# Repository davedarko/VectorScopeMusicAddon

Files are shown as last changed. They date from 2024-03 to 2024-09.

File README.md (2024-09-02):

# VectorScopeMusicAddon
A small add-on for the Hackaday Supercon 2023 / Europe 2024 event badge that allows displaying oscilloscope music!

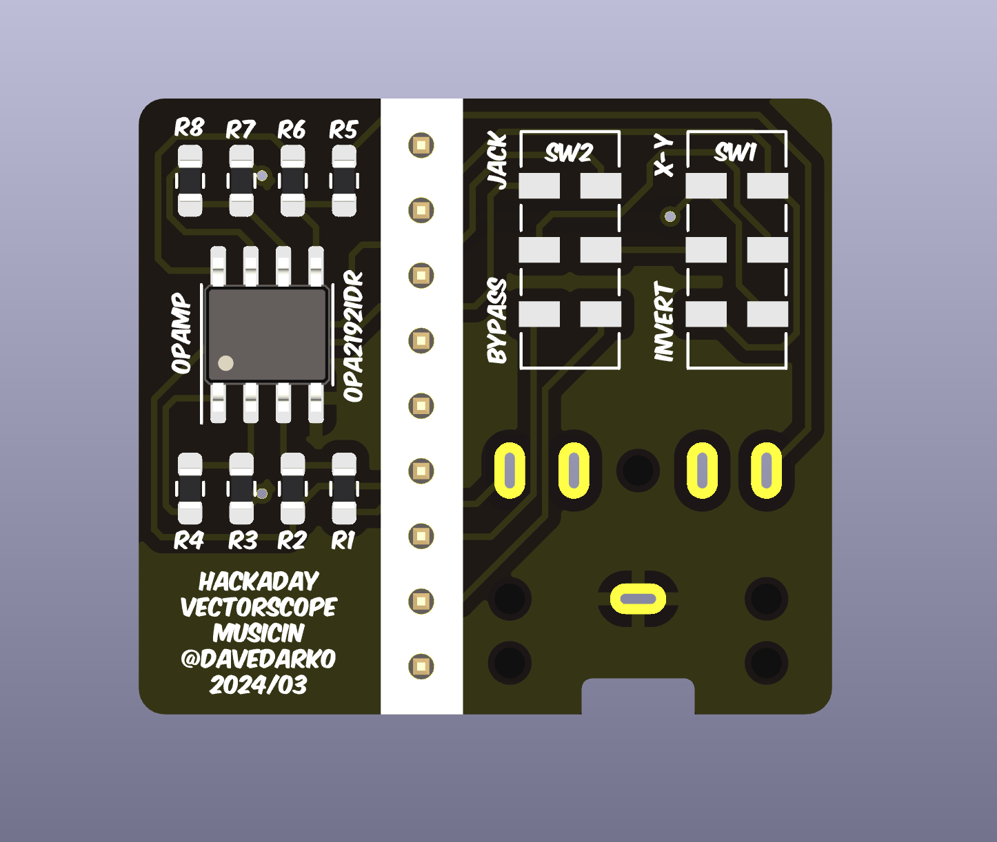
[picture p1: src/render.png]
Screenshot of KiCad render


## Design Notes
There's a switch to flip the x and y-axis. Due to the displays coordinate system being 0,0 top-left it means that the y-axis is mirrored or upside-down. To negate this in some way and not fiddle around with inverting signals, the switch rotates the image by 90 degrees. It might just be that one of my macbooks channels is inverted, I have to investigate.

## Errata
There's an easy fix for the vectorscope having an inverted y-axis, making the oscilloscope music show upside down. I've created a software PR that rotates and mirrors the display so it's looking correct on its own. Luckily the oscilloscope mode has running its own display instance, so it is one line of code to change.

https://github.com/Hack-a-Day/Vectorscope/pull/15

## BASIC-2
There's a wonderful case design for the badge done by @softegg. To fit into the badge better, I have designed another version with no parts on the left side of the pin header and mounting holes to create a small 3D printed cover to fit the theme better. With the known fix for the inverted y-axis, I have removed the switch to swap x and y axis now.

https://github.com/softegg/supercon-2023-badge-enclosure/

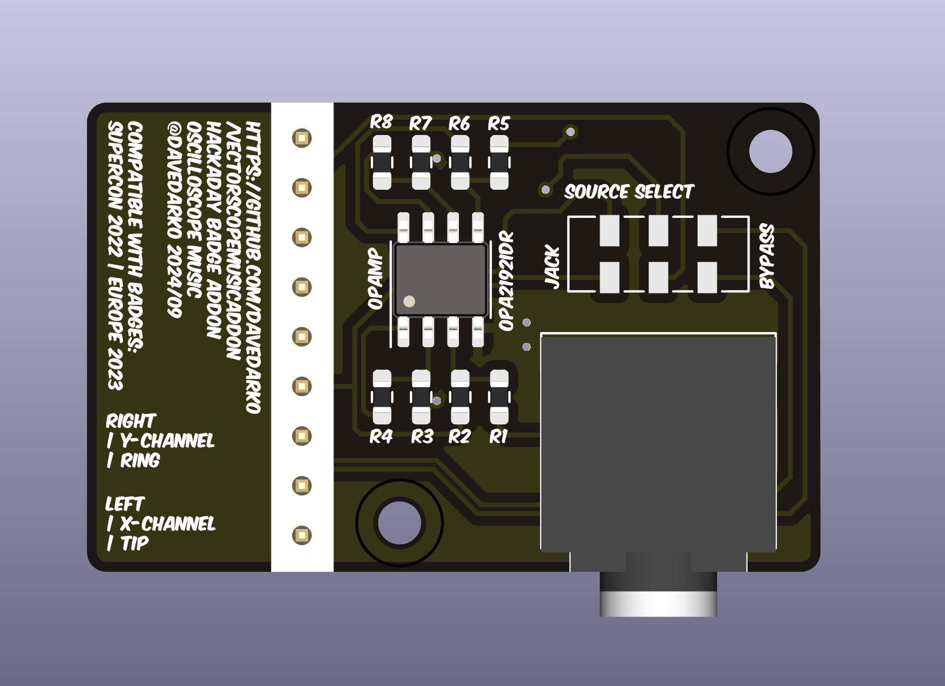
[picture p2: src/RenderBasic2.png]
Screenshot of KiCad render


## credits
- Hackaday's badge repo https://github.com/Hack-a-Day/Vectorscope
- schematics are heavily inspired by this post https://electronics.stackexchange.com/questions/37095/level-shifting-a-2-5v-signal-to-0-5v

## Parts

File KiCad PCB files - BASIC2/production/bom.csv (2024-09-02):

Designator | Footprint | Quantity | Value | LCSC Part #
J1 | PinHeader_1x09_P2.54mm_Vertical | 1 | Conn_01x09_Socket
J3 | Jack_3.5mm_CUI_SJ1-3525N_Horizontal | 1 | AudioJack3_SwitchTR
R1, R5 | 0603 | 2 | 10k
R2, R6 | 0603 | 2 | 33k
R3, R7 | 0603 | 2 | 13k
R4, R8 | 0603 | 2 | 15k
SW2 | SW_DPDT_CK_JS202011JCQN | 1 | SW_Push_DPDT | C221665
U1 | SOIC-8_3.9x4.9mm_P1.27mm | 1 | OPA2192 | C110074

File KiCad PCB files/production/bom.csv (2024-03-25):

Designator | Footprint | Quantity | Value | LCSC Part #
J1 | PinHeader_1x09_P2.54mm_Vertical | 1 | Conn_01x09_Socket
J3 | Jack_3.5mm_CUI_SJ1-3525N_Horizontal | 1 | AudioJack3_SwitchTR
R1 | 0603 | 1 | 10k
R2 | 0603 | 1 | 33k
R3 | 0603 | 1 | 13k
R4 | 0603 | 1 | 15k
R5 | 0603 | 1 | 10k
R6 | 0603 | 1 | 33k
R7 | 0603 | 1 | 13k
R8 | 0603 | 1 | 15k
SW1, SW2 | SW_DPDT_CK_JS202011JCQN | 2 | SW_Push_DPDT | C221665
U1 | SOIC-8_3.9x4.9mm_P1.27mm | 1 | OPA2192 | C110074

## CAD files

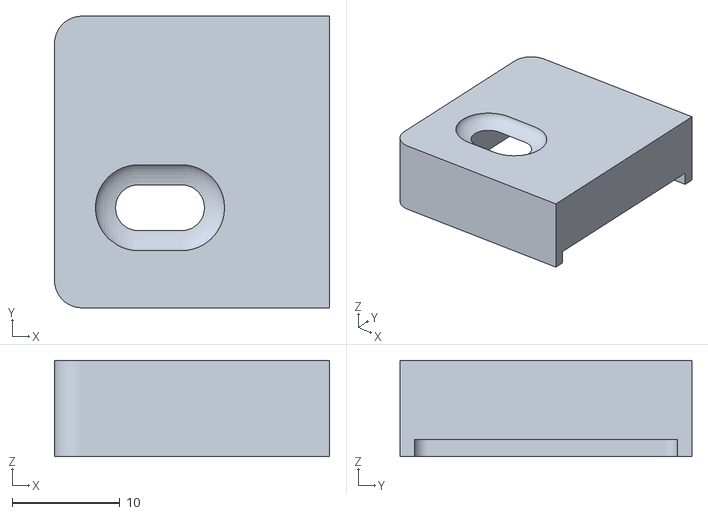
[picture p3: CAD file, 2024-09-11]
KiCad PCB files - BASIC2/Case/BASIC2.stl
25.5 x 27.1 x 8.95

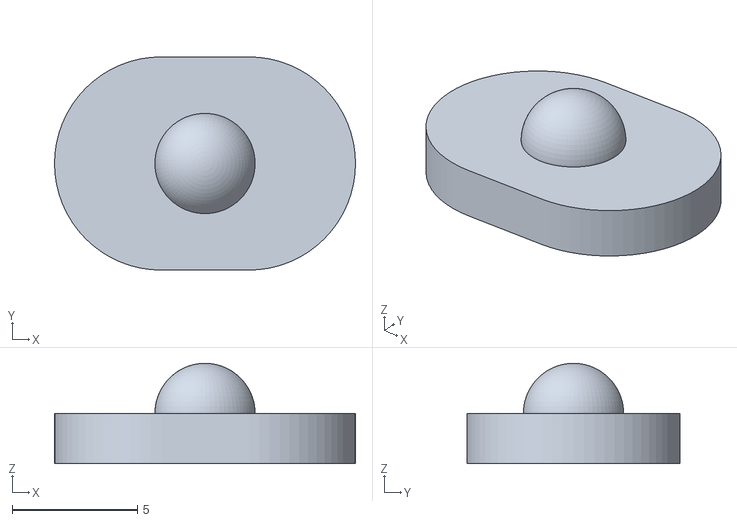
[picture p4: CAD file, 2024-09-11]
KiCad PCB files - BASIC2/Case/BASIC2_switch.stl
12.0 x 8.50 x 4.00

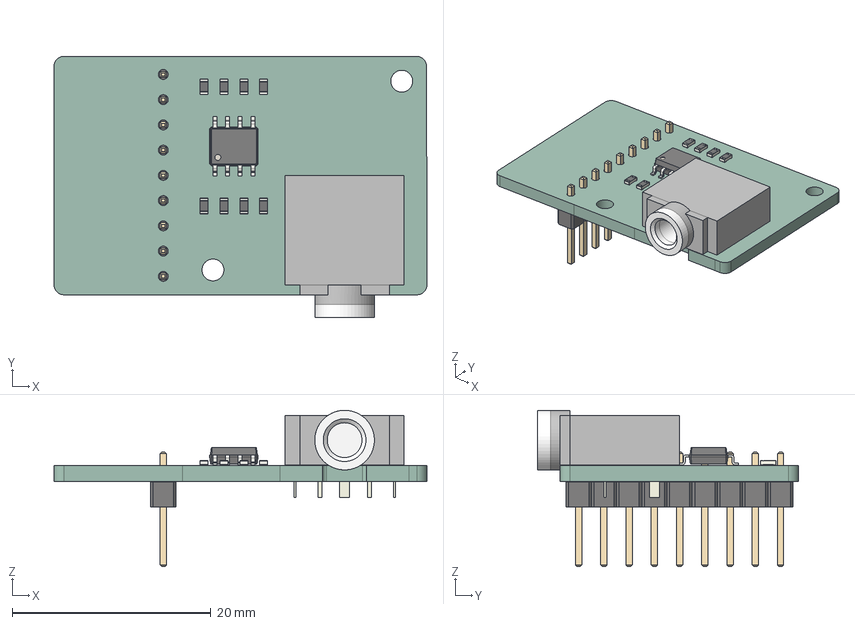
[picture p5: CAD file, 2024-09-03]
KiCad PCB files - BASIC2/Case/VectorScopeMusicAddon.step
37.5 x 26.3 x 15.7 mm
R_0603_1608Metric x 8
Jack_3.5mm_CUI_SJ1-3525N_Horizontal
SOIC_8_39x49mm_P127mm
PinHeader_1x09_P254mm_Vertical
VectorScopeMusicAddon_PCB

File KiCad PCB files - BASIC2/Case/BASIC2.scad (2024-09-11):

w = 37.5;
d = 24;
h = 1.6;
r = 1;
$fn = $preview ? 32 : 64;


t = 3 * .45; // thickness of walls
c = .2; // clearance
case =  t*2 + c*2;
ch = 6 + h + t; // - (r+t+c);


cube_w = 9;
cube_d = 3.7;
cube_h = 3.7;

button_w = 11;
button_d = 8.5;
button_h = 2;
button_r = button_d/2;
button_s = 2;
button_c = 1.8;
	

if($preview) {

	// PCB
	color("green")
	difference() {		
		rounded_box(w,d,h,r);
		
		translate([-w/2 + (w-35), -d/2 + 2.5, -1])
		cylinder(h+2, 1.1, 1.1);
		
		translate([-w/2 + (w-35) + 19, -d/2 + 2.5 + 19, -1])
		cylinder(h+2, 1.1, 1.1);
	}
	
	jack();
	
	// switch cutout
	translate([-cube_w/2 + w/2 -29.25,-cube_d/2 -d/2 +7.75, h]) 
	cube([cube_w,cube_d,cube_h]);
}

if(1) {

	color ([1,1,1,.3])
	// button
	translate([ button_s/2 + w/2 -29.25,-d/2 +7.75, h + cube_h]) {

		difference() {
			union() {
				rounded_box(button_w,button_d,button_h,button_r);
				
				translate([0,0,button_h])
				sphere(button_s);
			}
			
			
			translate([-button_c/2,-button_c/2,-1])
			cube([button_c, button_c, button_h + button_s/2 + 1]);
		}
	}
	 
}

// case
if (1)
color ([.1,.1,.1,.5]) {
	union () {

		difference() {

			union() {
				rounded_box(w + case, d + case, ch, r+ case/2);
				
				if (0) {
				// cylinder();
				translate([-w/2 + r, -d/2 + r, ch])
				sphere(r+case/2);
				
				translate([-w/2 + r, d/2 - r, ch])
				sphere(r+case/2);
				
				translate([-w/2  + r, d/2 - r, ch])
				rotate([0,90,0])
				cylinder(w, r+case/2, r+case/2);

				translate([-w/2  + r, -d/2 + r, ch])
				rotate([0,90,0])
				cylinder(w, r+case/2, r+case/2);

				translate([
					-(w + case)/2 +(r+t+c), 
					+(d + case)/2 -(r+t+c),
					ch
					])
				rotate([90,0,0])
				cylinder((d + case) - 2* (r+t+c) , r+case/2, r+case/2);

				}			
			}
			
			pill_w = 12;
			pill_r = 4;
			translate([pill_w/2 + w/2 -29.25, -d/2 +7.75, ch])
						scale([1,1,.4])
			rotate([0,-90,0])
				pill(pill_w, pill_r);


			
			translate([0, 0, -1]) 
			rounded_box(w + c*2, d + c*2, ch - t + 1, r + c);
			
			

			translate([ - w/2 + 24, -d, -1]) 	
			cube([2*w, 2*d, 2*ch +1]);
			
			jack();
		}
		
		// wall
		translate([1*.45 - t - w/2 + 24, -(d+case)/2,h])
		cube([t- 1*.45, d + case, ch-h]);

		// screw terminals
		difference() {
			translate([-w/2 + (w-35), -d/2 + 2.5, h])
			cylinder(ch-h, 2.5, 2.5);

			translate([-w/2 + (w-35), -d/2 + 2.5, h-1])
			cylinder(ch-h+2, .8, .8);
		}

		difference() {
			translate([-w/2 + (w-35) + 19, -d/2 + 2.5 + 19, h])
			cylinder(ch-h, 2.5, 2.5);

			translate([-w/2 + (w-35) + 19, -d/2 + 2.5 + 19, h-1])
			cylinder(ch-h+2, .8, .8);
		}
		
	}
}




// jack
module jack() {
	color("gray")
	translate([+w/2 -6 -29.25,0,h]) {
		cube([12,12,5]);
		
		translate([6, 12 + 3.3, 2.5])
		rotate([90,0,0])
		cylinder(3.3, 3.1, 3.1);
	}
}

module pill(h, r){
	translate([0,0,r]) {
		sphere(r);
		cylinder(h-r-r,r,r);
		translate([0,0,h-r-r])
		sphere(r);
	}
}

module rounded_box(w,d,h,r)
{
	union(){
		translate([-w/2+r, -d/2+r, 0]) cylinder(h, r, r);
		translate([-w/2+r, d/2-r, 0]) cylinder(h, r, r);
		translate([w/2-r, -d/2+r, 0]) cylinder(h, r, r);
		translate([w/2-r, d/2-r, 0]) cylinder(h, r, r);
		
		translate([-w/2+r, -d/2, 0]) cube([w-r*2,d,h]);
		translate([-w/2, -d/2+r, 0]) cube([w,d-r*2,h]);
	}
}

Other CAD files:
KiCad PCB files - BASIC2/Case/BASIC2_fillet.stl

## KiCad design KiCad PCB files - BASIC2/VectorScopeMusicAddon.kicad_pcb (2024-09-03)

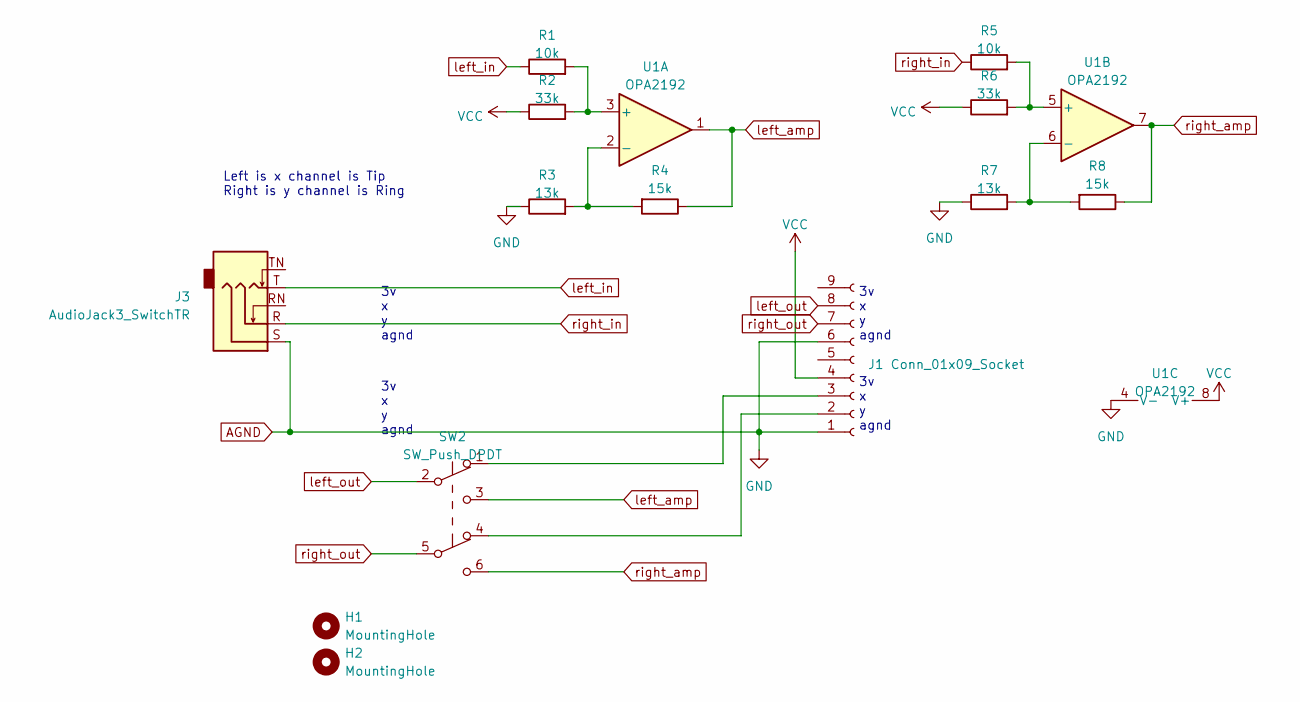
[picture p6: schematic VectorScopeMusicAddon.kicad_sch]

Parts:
H1, H2: MountingHole; MountingHole_2.2mm_M2
J1: Conn_01x09_Socket; PinHeader_1x09_P2.54mm_Vertical
J3: AudioJack3_SwitchTR; Jack_3.5mm_CUI_SJ1-3525N_Horizontal
R1, R5: 10k; R_0603_1608Metric_Pad0.98x0.95mm_HandSolder
R2, R6: 33k; R_0603_1608Metric_Pad0.98x0.95mm_HandSolder
R3, R7: 13k; R_0603_1608Metric_Pad0.98x0.95mm_HandSolder
R4, R8: 15k; R_0603_1608Metric_Pad0.98x0.95mm_HandSolder
SW2: SW_Push_DPDT; SW_DPDT_CK_JS202011JCQN; MPN C221665
U1: OPA2192; SOIC-8_3.9x4.9mm_P1.27mm; MPN C110074; JLCPCB Rotation Offset 90

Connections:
AGND: J1.1, J1.6, J3.S, R3.1, R7.1, U1.4 (V-)
unnamed: J1.2, SW2.4 (A)
unnamed: J1.3, SW2.1 (A)
unnamed: R1.2, R2.2, U1.3 (+)
unnamed: R3.2, R4.2, U1.2 (-)
unnamed: R5.2, R6.2, U1.5 (+)
unnamed: R7.2, R8.2, U1.6 (-)
VCC: J1.4, R2.1, R6.1, U1.8 (V+)
left_amp: R4.1, SW2.3 (C), U1.1
left_in: J3.T, R1.1
left_out: J1.8, SW2.2 (B)
right_amp: R8.1, SW2.6 (C), U1.7
right_in: J3.R, R5.1
right_out: J1.7, SW2.5 (B)

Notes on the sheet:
3v x y agnd
Left is x channel is Tip Right is y channel is Ring

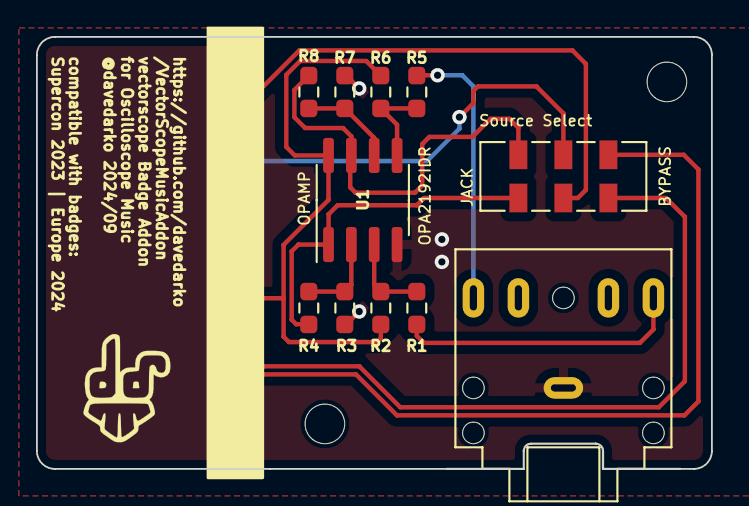
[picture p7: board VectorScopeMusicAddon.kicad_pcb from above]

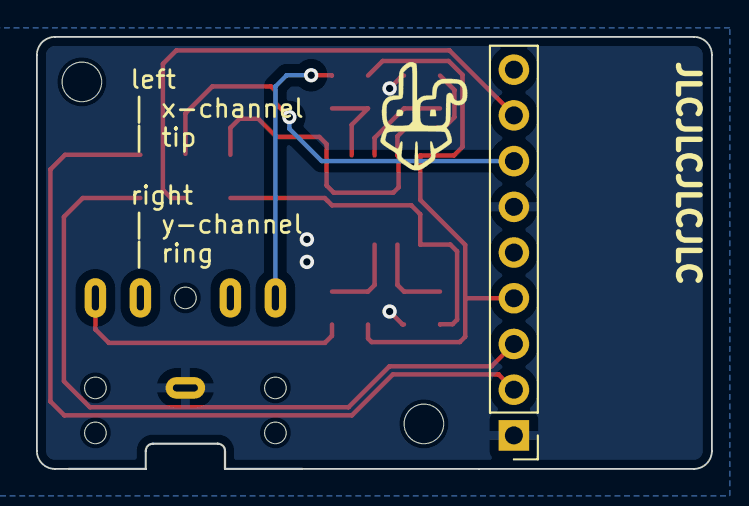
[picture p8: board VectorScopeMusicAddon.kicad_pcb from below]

Board: 2 copper layers, 37.5 x 24.0 mm, 16 parts (2 on the bottom side), 14 nets.

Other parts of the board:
Ref**: Val**; davedarko_logo_silk_outline
Ref**#2: Val**; davedarko_logo_silk_outline

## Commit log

2024-03-22 added PCB files
    [VectorScopeMusicAddon.kicad_sch]
2024-03-22 bom and resistor values
    [VectorScopeMusicAddon.kicad_sch, bom.csv, designators.csv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]
2024-03-25 added part values and render
    [VectorScopeMusicAddon.kicad_sch, bom.csv]
2024-04-09 inverted y-channel
    changed y-channel to be inverted by differential amplifier
    [VectorScopeMusicAddon.kicad_sch, bom.csv, positions.csv]
2024-04-18 Revert "inverted y-channel"
    This reverts commit 5a1fcf084c13772f6a73f50f0cc3052d495043d8.
    [VectorScopeMusicAddon.kicad_sch, bom.csv, positions.csv]
2024-09-02 added long version for Tina case
    [VectorScopeMusicAddon.kicad_pcb, VectorScopeMusicAddon.kicad_sch, bom.csv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]
2024-09-03 basic2 fonts
    [BASIC2.scad, BASIC2.stl, VectorScopeMusicAddon.kicad_pcb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]
2024-09-11 two styles
    [BASIC2.scad, BASIC2.stl, BASIC2_fillet.stl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]
